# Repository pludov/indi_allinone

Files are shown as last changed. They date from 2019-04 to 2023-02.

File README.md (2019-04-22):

# INDI AllInOne Arduino driver

## Introduction

This project provides software + hardware instructions to build a powerfull astronomy tool for astrophotography, including focuser, filterwheel, dew heater, humidity sensor, ...

All that hardware is driven by a single Teensy 3.2 board (any 3.3v Arduino with > 32k memory and enough PINs should do it. Mega2560 is also possible with small adaptations to the schematics for 5v).

Contrary to most similar projects, the logic is fully operated within the micro-controler, so it is very easy to add/modify features. There is no ping-pong between firmware and driver. That also means that you can quickly write code for new hardware without knowing too much about INDI driver. Exposes an INDI property, write code that reacts to its change and you're done. And thanks to the INDI protocol, you'll end up with a UI integration within your favorite astro software !

It is intended to be used together with an ARM board, via serial TTL. However, it can be quickly adapted to run over usb serial as well.

I personnaly use it with [Mobindi](https://github.com/pludov/mobindi), my other Astrophoto project, making a full lightweight astro setup, controlled from a single mobile phone.

## Quick start

### Building/Customizing the firmware

The firmware can be compiled using the Arduino IDE, and source code is very modular, making it easy to add your own hardware (more/less dewheater, ...) If you want to do so, open ucontroler.ino and locate the function "declareHardware".

The setup includes:
* Focuser (unipolar motor)
* Fitlerwheel (unipolar motor with hall sensor)
* DHT22 sensor (temperature/humidity)
* 2x DewHeater (PWM with temperature sensor)
* Watt/Current metter to monitor power consumption
* A clock to report uptime (& detect reset/crash)

You can tweak motor acceleration/speed for focuser and filterwheel. The default is conservative, with lower speed for focuser retractation (usefull if you have a refractor)

If you want to adapt for an unsupported hardware, you'll need to write an event driven class (ie avoid blocking for more than about 1 ms, to keep filterwheel/focuser happy). A good starting point is Status.h/Status.cpp that just reports a numeric value.

Focuser.cpp also has a simple example of how to control something from INDI property.

### Building the indi driver

The indi driver is just a relay to the micro-controler, meaning you probably won't have to modify it.

To build, issue the commands:
```shell
cd indi_driver
mkdir build
cd build
cmake ..
make
sudo make install
```

You'll now have a indi_allinone driver installed.

### Building the hardware

The electronics schematic are provided for Teensy 3.2.

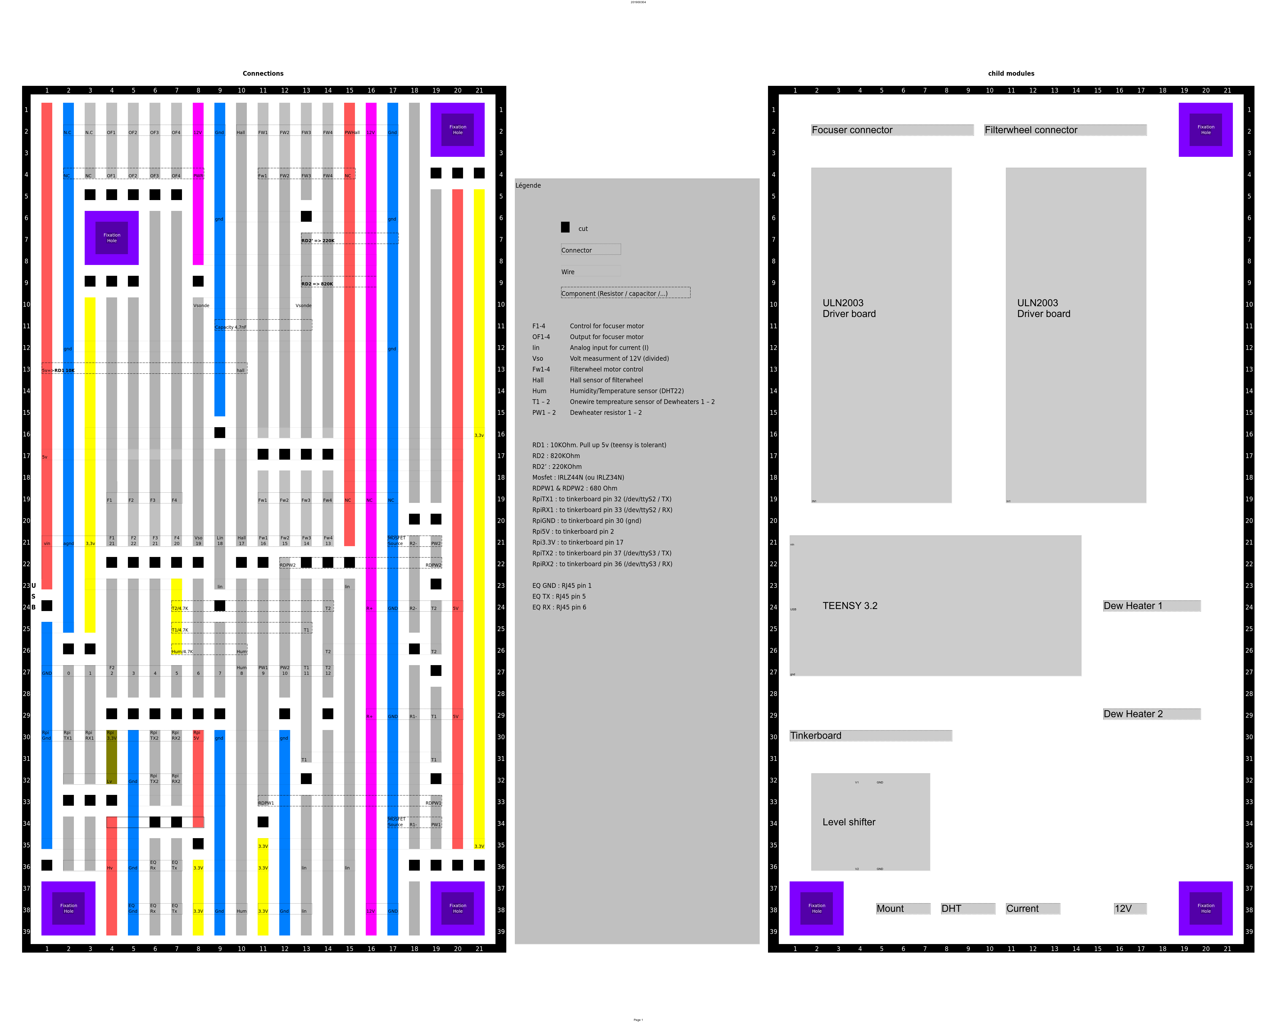
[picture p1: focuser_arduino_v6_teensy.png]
Schematics


The resulting board has roughtly the size of a raspberry pi, meaning you can probably stack them in a small box.

The filterwheel can be made from a manual filterwheel, adding a BYJ48 stepper and a hall sensor + magnet for calibration.
More details here (french) : http://pludov.blogspot.com/2016/08/roue-filtre-motorisee-la-mecanique.html

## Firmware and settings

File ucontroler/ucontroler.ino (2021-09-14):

// Indi All-in-one Arduino Driver
// @2019 Ludovic Pollet
//
// Release history:
// 
//------------------------------------------------------------------

#include <Arduino.h>


// Include necessary libraries
#include <OneWire.h>                          // DS18B20 temp sensor
#include <DallasTemperature.h>                // DS18B20 temp sensor
#include <EEPROM.h>                           // EEPROM Library

#include "CommonUtils.h"
#include "EepromStored.h"
#include "IndiProtocol.h"
#include "ScheduledIndiProtocol.h"
#include "IndiVector.h"
#include "IndiVectorMember.h"
#include "XmlWriteBuffer.h"
#include "BinSerialReadBuffer.h"

#include "utime.h"
#include "BaseDriver.h"
#include "Focuser.h"
#include "FilterWheel.h"
#include "Scheduler.h"
#include "pwmresistor.h"
#include "Status.h"
#include "MeteoTemp.h"
#include "DewHeater.h"
#include "WattMeter.h"


// --------------------------------------------------------------
// Declaration of hardware interfaces
// --------------------------------------------------------------
void declareHardware(BaseDriver * baseDriver) {

	// DHT22 sensor on pin8
	MeteoTemp * meteoTemp = new MeteoTemp(8, DHT22);

	// DewHeater with sensor on pin 11 & pwm on pin 9
	DewHeater * dw = new DewHeater(meteoTemp, 11, 9, 1);
	// another dewHeater with sensor on pin 12 & pwm on pin 10
	DewHeater * dw2 = new DewHeater(meteoTemp, 12, 10, 2);

	// Measure voltage on pin 5 and current on pin 4
	new WattMeter(5, 4, 0, EepromStored::Addr(1));

	// Focuser motor - 4 pins for motor control
	static const uint8_t focuserMotorPins[4] = { A6, A7, A8, A9 };
	new Focuser(baseDriver, EepromStored::Addr(4), focuserMotorPins, 0);

	// Focuser motor - 4 pins for motor control + 1 for hall sensor
	static const uint8_t filterWheelPins[5] = { 13, 14, 15, 16, 17};
	new FilterWheel(baseDriver, EepromStored::Addr(3), filterWheelPins, 0);

	// Report uptime
	new Status();
}

//------------------------------------------------------------------
// Setup
//------------------------------------------------------------------
void setup() {
	// initialize serial for ASCOM
	Serial.begin(115200);
	Serial1.begin(115200);
	DEBUG(F("Init!"));

	delay(500);

	BaseDriver * baseDriver = new BaseDriver();
	declareHardware(baseDriver);

	// Read eeprom
	EepromStored::init();

	// Let's talk packed indi over a serial link
#ifdef __AVR_ATmega2560__
	ScheduledIndiProtocol * serialWriter = new ScheduledIndiProtocol(&Serial);
#else
	ScheduledIndiProtocol * serialWriter = new ScheduledIndiProtocol(&Serial1);
#endif
	DEBUG(F("Welcome!"));
}

//------------------------------------------------------------------
// Main Loop
//------------------------------------------------------------------
void loop() {
	Scheduler::instance().loop();
}

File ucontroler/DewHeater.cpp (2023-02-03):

#include <Arduino.h>

#include "DewHeater.h"
#include "MeteoTemp.h"
#include "Utils.h"
#include "CommonUtils.h"
#include "EepromStored.h"
#include "IndiVectorMemberStorage.h"

#define STATUS_NEED_SCAN 0
#define STATUS_MEASURE 1
#define STATUS_IDLE 2

#define CONTROL_OFF 0
#define CONTROL_PWM_LEVEL 1
#define CONTROL_TARGET_TEMP 2
#define CONTROL_DEW_POINT_DELTA 2

#define STORED_ADDR_LENGTH 7
#define STORED_NAME_LENGTH 8

struct Settings {
	uint8_t opMode;
	uint8_t addr[STORED_ADDR_LENGTH];
	char name[STORED_NAME_LENGTH];
	float kp, ki, kd;
	float targetPwm, targetTemp, targetTempAbove;

	bool matchAddr(const uint8_t * taddr)
	{
		for(int i = 0; i < STORED_ADDR_LENGTH; ++i) {
			if (addr[i] != taddr[i]) return false;
		}
		return true;
	}

	void clearAddr()
	{
		for(int i = 0; i < STORED_ADDR_LENGTH; ++i) {
			addr[i] = 0;
		}
	}

	bool isEmptyAddr() {
		for(int i = 0; i < STORED_ADDR_LENGTH; ++i) {
			if (addr[i]) return false;
		}
		return true;
	}

	void setName(const char * v)
	{
		int i = 0;
		while(i < STORED_NAME_LENGTH) {
			char c = v[i];
			name[i] = c;
			i++;
			if (!c) break;
		}
		while(i < STORED_NAME_LENGTH) {
			name[i] = 0;
			i++;
		}
	}
};

const int storedSettingsCount = 3;

class DewHeatersMemory : public EepromStored {
private:
	static DewHeatersMemory * instance;
protected:

	virtual void decodeEepromValue(void * buffer, uint8_t sze){
		if (sze != getEepromSize()) {
			DEBUG(F("DewHeater EEPROM invalid size"), sze);
			return;
		}
		memcpy(settings, (void*)buffer, sze);
	}

	virtual void encodeEepromValue(void * buffer, uint8_t sze) {
		if (sze != getEepromSize()) return;
		memcpy(buffer, (void*)settings, sze);
	}

	virtual int getEepromSize() const {
		return sizeof(Settings) * storedSettingsCount;
	}

	// Bit mask of known slots (not saved)
	uint8_t slotSeen;
	Settings * settings;

	int8_t findPos(const uint8_t * addr) const
	{
		for(int i = 0; i < storedSettingsCount; ++i)
		{
			DEBUG(F("Eeprom: "), settings[i].addr[0], settings[i].addr[1], settings[i].addr[2], settings[i].addr[3], settings[i].addr[4]);
			if (settings[i].matchAddr(addr)) {
				return i;
			}
		}
		return -1;
	}

	int8_t findNewSlot() const
	{
		// Find an empty slot
		for(int i = 0; i < storedSettingsCount; ++i)
		{
			if (settings[i].isEmptyAddr()) {
				return i;
			}
		}

		// Select the last seen item ?
		for(int i = 0; i < storedSettingsCount; ++i) {
			if (!(slotSeen & (1 << i))) {
				return i;
			}
		}
		return 0;
	}

public:
	DewHeatersMemory(uint32_t addr): EepromStored(addr) {
		settings = new Settings[storedSettingsCount];
		slotSeen = 0;
	}

	void save(const Settings & newSettings)
	{
		int8_t slot = findPos(newSettings.addr);
		if (slot == -1) {
			slot = findNewSlot();
		}
		DEBUG(F("Saving to slot"), slot);
		// Don't overwrite now...
		slotSeen |= (1 << slot);
		memcpy((void*)(settings + slot), (const void*)&newSettings, sizeof(Settings));

		write();
	}

	void forget(uint8_t * addr)
	{
		int8_t slotId = findPos(addr);
		if (slotId == -1) {
			return;
		}
		// Just clear the addr
		settings[slotId].clearAddr();
		write();
	}


	const Settings * find(uint8_t * addr)
	{
		DEBUG(F("Looking for "), addr[0], addr[1], addr[2], addr[3], addr[4]);
		int8_t slotId = findPos(addr);
		if (slotId == -1) {
			return nullptr;
		}
		slotSeen |= (1 << slotId);
		return settings + slotId;
	}

	static DewHeatersMemory * getInstance() {
		if (instance == nullptr) {
			instance = new DewHeatersMemory(EepromStored::Addr(2));
		}
		return instance;
	}
};

DewHeatersMemory * DewHeatersMemory::instance = nullptr;



// Operating modes:
//   - Forced (targetPwm 0 -> 100%)
//   - target temperature (use pid to targetTemp)
//   - above dew point (use pid to stay a fixed °C above dewpoint
// This misses a "save" button
DewHeater::DewHeater(MeteoTemp * meteoTemp, uint8_t pin, uint8_t pwmPin, int suffix)
    :Scheduled(F("DewHeater")),
    group(Symbol(F("DEW_HEATER"), suffix)),

	statusVec(group, Symbol(F("DEW_HEATER_INFO_TEMP"), suffix), F("HW Temperature")),
    temperature(&statusVec, F("DEW_HEATER_TEMP_VALUE"), F("Readen Temper (C)"),-273.15, 100, 1),
    pwm(&statusVec, F("DEW_HEATER_PWM_LEVEL"), F("Power applied (%)"),0, 100, 1),
	dynTargetTemp(&statusVec, F("DEW_HEATER_CURR_TARGET_TEMP"), F("Target Temp (C)"), -273.15, 100, 1),

    uidVec(group, Symbol(F("DEW_HEATER_INFO_UID"), suffix), F("Unique Identifier")),
    uid(&uidVec, F("DEW_HEATER_UID_VALUE"), F("Unique Identifier"),12),

    nameVec(group, Symbol(F("DEW_HEATER_INFO_NAME"), suffix), F("Label"), VECTOR_WRITABLE|VECTOR_READABLE),
    name(&nameVec, F("DEW_HEATER_INFO_NAME"), F("Label"),STORED_NAME_LENGTH),

	powerMode(group, Symbol(F("DEW_HEATER_POWER_MODE"), suffix), F("Power Mode"), VECTOR_WRITABLE|VECTOR_READABLE),
	powerModeOff(&powerMode, F("POWER_MODE_OFF"), F("Off")),
	powerModeForced(&powerMode, F("POWER_MODE_FORCED"), F("Forced")),
	powerModeByTemp(&powerMode, F("POWER_MODE_BY_TEMP"), F("Target temp")),
	powerModeOverDew(&powerMode, F("POWER_MODE_OVER_DEW"), F("Follow dew point")),


	targetPwmVec(group, Symbol(F("DEW_HEATER_TARGET_PWM"),suffix), F("Fixed Power"), VECTOR_WRITABLE|VECTOR_READABLE),
	targetPwm(&targetPwmVec, F("TARGET_PWM"), F("0-100"), 0, 100, 0.1),

	targetTempVec(group, Symbol(F("DEW_HEATER_TARGET_TEMP"),suffix), F("Fixed Temperature"), VECTOR_WRITABLE|VECTOR_READABLE),
	targetTemp(&targetTempVec, F("TARGET_TEMPERATURE"), F("C"), -100, 100, 0.1),

	targetTempAboveVec(group, Symbol(F("DEW_HEATER_TARGET_TEMP_ABOVE_DP"),suffix), F("Above Dew Point"), VECTOR_WRITABLE|VECTOR_READABLE),
	targetTempAbove(&targetTempAboveVec, F("TARGET_TEMPERATURE_ABOVE_DP"), F("C"), -100, 100, 0.1),

	settingKpVec(group, Symbol(F("DEW_HEATER_PID_P"), suffix), F("PID Settings - P"), VECTOR_WRITABLE|VECTOR_READABLE),
	settingKp(&settingKpVec, F("P"), F("P"), -1000, 1000, 0.1),

	settingKiVec(group, Symbol(F("DEW_HEATER_PID_I"), suffix), F("PID Settings - I"), VECTOR_WRITABLE|VECTOR_READABLE),
	settingKi(&settingKiVec, F("I"), F("I"), -1000, 1000, 0.1),

	settingKdVec(group, Symbol(F("DEW_HEATER_PID_D"), suffix), F("PID Settings - D"), VECTOR_WRITABLE|VECTOR_READABLE),
	settingKd(&settingKdVec, F("D"), F("D"), -1000, 1000, 0.1),

	configOperationVec(group, Symbol(F("DEW_HEATER_CONFIG_OPERATION"), suffix), F("Eeprom"), VECTOR_WRITABLE|VECTOR_READABLE),
	configIdle(&configOperationVec, F("IDLE"), F("Idle")),
	configSave(&configOperationVec, F("SAVE"), F("Save")),
	configForget(&configOperationVec, F("FORGET"), F("Forget")),
	configReload(&configOperationVec, F("RELOAD"), F("Reload")),

    oneWire(pin)
{
	this->meteoTemp = meteoTemp;
    this->priority = 2;
    this->status = 0;
    this->pwmPin = pwmPin;
    this->failed();
    this->nextTick = UTime::now();
    ITerm = 0;
    pidRunning = false;
    pidDisabled = false;
    tempAvailable = false;
    lastTime = 0;
    lastInput = 0;
    ITerm = 0;

    // Ensure config item is available
    DewHeatersMemory::getInstance();
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

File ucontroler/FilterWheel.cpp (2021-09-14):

#ifdef ARDUINO
#include <Arduino.h>
#endif

#include <string.h>

#include "CommonUtils.h"
#include "FilterWheel.h"
#include "BaseDriver.h"
#include "EepromStored.h"
#include "IndiVectorMemberStorage.h"

#define DEFAULT_MOTOR_PULSE 4000

#define POS_INVALID ((uint32_t)0x7fffffff)

struct Settings {
	uint32_t pos;
    // Base of the last calibration
    uint8_t base;
};

class FilterWheelMemory : public EepromStored {
protected:
	virtual void decodeEepromValue(void * buffer, uint8_t sze){
		if (sze != sizeof(Settings)) {
			DEBUG(F("FilterWheel EEPROM invalid size"), sze);
			return;
		}
		memcpy(&settings, (void*)buffer, sze);
	}

	virtual void encodeEepromValue(void * buffer, uint8_t sze) {
		if (sze != sizeof(Settings)) return;
		memcpy(buffer, (void*)&settings, sze);
	}

	virtual int getEepromSize() const {
		return sizeof(Settings);
	}
public:
	// Bit mask of known slots (not saved)
	Settings settings;

	FilterWheelMemory(uint32_t addr): EepromStored(addr) {
		settings.pos = POS_INVALID;
        settings.base = 0;
	}

	void save()
	{
		write();
	}
};

FilterWheel::FilterWheel(BaseDriver * bd, uint32_t addr, const uint8_t* pins, int suffix)
:
    Motor(pins, F("Filterwheel"), DEFAULT_MOTOR_PULSE, DEFAULT_MOTOR_PULSE),
    group(Symbol(F("FILTERWHEEL"), suffix)),
    filterSlotVec(group, Symbol(F("FILTER_SLOT"), suffix), F("Filter Slot"), VECTOR_WRITABLE|VECTOR_READABLE),
    filterSlot(&filterSlotVec, F("FILTER_SLOT_VALUE"), F("Filter"), 0, FILTER_SLOT_COUNT - 1, 1),
    rawPosVec(group, Symbol(F("FILTER_RAW_POSITION"), suffix), F("Raw Position"), VECTOR_WRITABLE|VECTOR_READABLE),
    rawPos(&rawPosVec, F("FILTER_RAW_POSITION"), F("Ticks"), 0, 100000, 1),
    motorSettingsVec(group, Symbol(F("FILTER_MOTOR_SETTINGS"), suffix), F("Motor settings"), VECTOR_WRITABLE|VECTOR_READABLE),
    motorPulse(&motorSettingsVec, F("FILTER_MOTOR_PULSE"), F("pulse (ms)"), 100,100000, DEFAULT_MOTOR_PULSE),
    motorBacklash(&motorSettingsVec, F("FILTER_MOTOR_BACKLASH"), F("backlash"), -10000,10000, 0),
    calibrateVec(group, Symbol(F("FILTER_CALIB"), suffix), F("Calibration"), VECTOR_WRITABLE|VECTOR_READABLE|VECTOR_SWITCH_ATMOSTONE),
    calibrate(&calibrateVec, F("CALIB"), F("Calibrate")),
    abortMotionVec(group, Symbol(F("FILTER_ABORT_MOTION"), suffix), F("Abort Motion"), VECTOR_WRITABLE|VECTOR_READABLE|VECTOR_SWITCH_ATMOSTONE),
    abortMotion(&abortMotionVec, F("ABORT"), F("Abort")),
    filterNamesVec(group, Symbol(F("FILTER_NAME"), suffix), F("Names"), VECTOR_WRITABLE|VECTOR_READABLE),
    filterPositionsVec(group, Symbol(F("FILTER_POS")), F("Positions"), VECTOR_WRITABLE|VECTOR_READABLE),
    hallVec(group, Symbol(F("FILTER_HALL"), suffix), F("Hall sensor"), VECTOR_READABLE),
    hall(&hallVec, Symbol(F("HALL_VALUE")), F("Value"),0 ,255, 1),
    eepromReadyListener(EepromCallback(&FilterWheel::loadInitialSettings, this))
{
    memory = new FilterWheelMemory(EepromStored::Addr(addr, 47));
    pauseAfterMove = 100;
    maxAccelStep = 30;
    for(int i = 0; i < FILTER_SLOT_COUNT; ++i) {
        filterNames[i] = new IndiTextVectorMember(&filterNamesVec,
                                        Symbol(F("FILTER_SLOT_NAME_"), i+1),
                                        Symbol(F("Filter"), i+1),
                                        9);
        IndiVectorMemberStorage::remember(filterNames[i], EepromStored::Addr(addr, 56+i));
        filterPositions[i] = new IndiIntVectorMember(&filterPositionsVec,
                                        Symbol(F("FILTER_SLOT_POS_"), i+1),
                                        Symbol(F("Filter"), i+1),
                                        0,
                                        100000,
                                        1);
        IndiVectorMemberStorage::remember(filterPositions[i], EepromStored::Addr(addr, 48+i));
    }
    IndiVectorMemberStorage::remember(&motorPulse, EepromStored::Addr(addr, 46));
    IndiVectorMemberStorage::remember(&motorBacklash, EepromStored::Addr(addr, 45));
    this->currentCalibration = CALIBRATION_IDLE;

    pinMode(this->motorPins[4], INPUT);
    loadPosition(50000, 0);
    onProgress();
    rawPosVec.onRequested(VectorCallback(&FilterWheel::rawPosChanged, this));
    filterSlotVec.onRequested(VectorCallback(&FilterWheel::filterSlotChanged, this));
    motorSettingsVec.onRequested(VectorCallback(&FilterWheel::motorSettingsChanged, this));
    abortMotionVec.onRequested(VectorCallback(&FilterWheel::abortChanged, this));
    calibrateVec.onRequested(VectorCallback(&FilterWheel::calibrateChanged, this));
    bd->addCapability(FILTER_INTERFACE);
}

void FilterWheel::loadInitialSettings()
{
    if (memory->settings.pos == POS_INVALID) {
        // Will stay idle in calibration state
        this->currentCalibration = 2;
    } else {
        this->currentCalibration = CALIBRATION_IDLE;
        loadPosition(memory->settings.pos, memory->settings.base);
        if (this->isMoving()) {
            setTargetPosition(getCurrentPosition());
        }
    }
    this->motorSettingsChanged();
    onProgress();
}

void FilterWheel::rawPosChanged() {
    if (this->currentCalibration) {
        // Busy - Ignore for now
        return;
    }
    gotoRawPos(rawPos.getValue());
}

void FilterWheel::gotoRawPos(int32_t target) {
    int32_t backlash = motorBacklash.getValue();
    int32_t intermediate = target;
    int32_t current = getCurrentPosition();
    if (backlash != 0) {
        if (backlash > 0) {
            if (target < current) {
                intermediate = target - backlash;
                if (intermediate < 0) {
                    intermediate = 0;
                }
            }
        } else {
            if (target > current) {
                intermediate = target - backlash;
            }
        }
    }
    if (target < 0) {
        target = 0;
    }
    if (intermediate < 0) {
        intermediate = 0;
    }
    this->setTargetPosition(target, intermediate);
}

void FilterWheel::motorSettingsChanged() {
    this->updatePulse(motorPulse.getValue(), motorPulse.getValue());
}

void FilterWheel::filterSlotChanged() {
    if (this->currentCalibration) {
        // Busy - ignore for now
        return;
    }
    int32_t newValue = filterSlot.getValue();
    if (newValue < 1 || newValue > FILTER_SLOT_COUNT) {
        newValue = 1;
        filterSlot.setValue(1);
    }
    int32_t target = filterPositions[newValue - 1]->getValue();
    gotoRawPos(target);
}

void FilterWheel::abortChanged() {
    if (this->abortMotion.getValue()) {
        abortMotion.setValue(false);
        this->currentCalibration = CALIBRATION_IDLE;
        if (this->isMoving()) {
            setTargetPosition(getCurrentPosition());
        }
        onProgress();
    }
}

bool FilterWheel::readPin() {
    return digitalRead(this->motorPins[4]);
}
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

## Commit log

2017-11-08 Migrated from previous code => compilate on Teennsy (probably broken)
    [MeteoTemp.cpp, Motor.cpp]
2017-11-10 Version limitée qui s'execute sur teensy
2017-11-10 Notification des changements sur les variables
2017-11-11 DS18b20 sensor driver
2017-11-11 DewHeater now reports UID of the sensor
2017-11-12 New PWM display
2017-11-12 Indi driver skeleton
2017-11-12 indi driver exposes serial connection parameters
2017-11-12 Demo for code sharing between arduino and indi driver
2017-11-17 Isolate XML code (debug on arduino)
2017-11-18 Bi-di comm, not ready
2017-11-19 Fix random data corruption + debug on Serial1
    [DewHeater.cpp, MeteoTemp.cpp, Motor.cpp]
2017-11-25 Properties are now removed on disconnect (+processing threads stop before closing serial)
2017-11-26 Support for switch vector (one of many only)
2017-11-26 DewHeater uses a switch
2017-11-26 Symbol now has its own class for Arduino and Indi driver
2017-11-26 Correct handling of group attribute of properties
    [DewHeater.cpp]
2017-12-02 Read dht22 sensor info
2017-12-09 Compilation fix for Eeprom on Teensy
2017-12-19 DewHeater and Meteo sensor progress
2017-12-19 USB serial is now for DEBUG only. Rely on HW serial 1 for Tinker board comm
2017-12-21 PID implementation for dew heater
2017-12-27 DewHeater: identify heaters using sensor unique id
2018-02-24 Fix dew heater identification: Limit eeprom items to approx ~255 bytes
2018-03-11 Fix DEW HEATER memory
    [DewHeater.cpp]
2018-09-29 Send debug logs from driver to indiserver
2018-12-15 Reports driver interface for Focuser
2018-12-31 Support for vector of independant switches
2019-04-19 FilterWheel without calibration and pos memory
2019-04-19 FilterWheel: calibration ok. Now misses backlash setting
    [FilterWheel.cpp]
2019-04-20 Fix filterwheel writing to eeprom before eeprom init
    [FilterWheel.cpp]
2019-04-21 Filterwheel sets filter pos on startup from EEPROM
2020-07-31 Fix obvious compilation problems not reported until now
    [Motor.cpp, ucontroler.ino]
2021-06-26 Fix for negative temperature
    [DewHeater.cpp]
2021-06-26 Attempt to handle motor backlash for fw
    [FilterWheel.cpp, Motor.cpp]
2021-06-27 Indi settings for FW motor (speed, backlash)
    [FilterWheel.cpp]
2021-06-27 Filterwheel keeps the low 8 bits accross calibration
    The state of the motor was discard after calibration.
    This was introducing 7/8 * 360° of imprecision on the motor axis.
    We are now limited to accuracy of gear box.
2021-09-14 Apply backlash when manually stepping filterwheel
    [FilterWheel.cpp]
2021-09-14 Fix micro step precision accros restart
    [Motor.cpp]
2021-09-14 Fix memory used before allocation
    [FilterWheel.cpp, Focuser.cpp]
2023-02-03 Motor config for the focuser
2023-03-19 A first plateform.IO convertion
2023-03-19 Compil but do not run on pico
2023-03-26 Fix disconnection of the indi driver
2023-04-01 Force default pwm to 255 on pico
2023-04-02 Keep heater measure under 1ms
2023-04-08 Run with 2 uart over usb (proto & debug)
2023-04-08 Fix DHT code hanging on pico
    [MeteoTemp.cpp]
2023-04-08 Distinct meteo drivers for BME & DHT
2023-11-02 Schematics for new board
    [AstroController2_20231102_1.fzz, Filterwheel.fzz, Focuser.fzz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]
2023-11-03 Preliminary case
    [case.scad]
2023-11-03 case progress
    [case.scad]
2023-11-04 Case is complete (untested)
    [case.scad]
2023-11-04 Case: RJ window, try 2
    [case.scad]
2023-11-04 Vixen fixation
    [case.scad]
2023-11-05 Everything laid out for case
    [case.scad]
2023-11-10 Stronger cover
    [case.scad]
2023-11-17 Extract the meteo opening for faster print
    [case.scad]
2023-11-19 Case improvment following first printing
    [case.scad]
2023-11-22 Usb hole for cable prevents collision with sadle
    [case.scad]
2023-11-22 Adjust pins for the pico version
2023-12-18 Heater schematics update
    [Heather-connection.fzz]
2023-12-22 Pico: put code into RAM to allow transparent flash access
2023-12-22 Pico: blink a led to notify status
2023-12-22 Use latest pico hardware
2023-12-22 Tickness of PCB
    [case.scad]
2023-12-22 Button to reboot in firmware mode
2024-01-17 Temperature compensation on the meteo sensor
2025-07-29 Hub support
    [support_hub.scad]
2025-08-02 Remove RJ45 & adapt to DC adapteur from amazon
    https://www.amazon.fr/dp/B08T8658H8?ref=ppx_yo2ov_dt_b_fed_asin_title&th=1
    [case.scad]
2025-08-02 System de fixation pour le petit hub
    Beaucoup plus simple. On laisse deux trou dans le boitier pour des languettes
    [case.scad]
2025-08-02 Fixation vixen via adaptateur rouge
    [case.scad]
2025-08-02 Vertical align of the usb hub fixation
    [case.scad]
2025-08-03 Fix vixen screws not traversing the cover
    [case.scad]
2025-08-03 Fix hub width evaluation
    [case.scad]
2025-08-03 Fixation pour le hub 4 ports (à base de visses M3)
    [support_hub_4port.scad]
2025-08-04 Revert "Pico: put code into RAM to allow transparent flash access"
    This reverts commit 54ab543043aa375021bdc66cfa374e6f61d51514.
    Flash function anyway force the other core to go idle. Better have serialization
    of the time critical method in core1 + live with the occasional ms delay on core0
2025-08-06 Reapply "Pico: put code into RAM to allow transparent flash access"
    This reverts commit 46dce69b1fb030674e0735f3b8249f9617d5974a.
2025-08-06 Adapting the ld script to latest pico framework version
    * Renommer text en flashtext
    flashtext: il n'y a pas de > FLASH coté copy_to_ram. C'est bizarre. Je l'ai laissé
    * et en retirer tout après (*(.reset))
    * retirer rodata de rodata
    remarque il y a aussi big_const. Verifier qu'on va le mettre
    * Mettre un .text just avant .data (verbatim par rapport à la version du sdk pico)
    => dedans il y a __ram_text_start__, __ram_text_end__, ... quoi en faire ?
    Ils sont probablement inutilisés.
    * à la fin du data, on ajoute les pre-init, init et f-init
    * .bss passe en LOAD.
2025-08-07 Ignore stl files
2025-08-07 BME sensor tries both i2c addresses
2025-08-07 Fix a potential bug with NAN (when meteo sensor malfunctions)
2025-08-09 Print RJ12 window
2025-08-09 Adaptation du support bme au nouveau PCB
2025-08-10 Pad de 3mm, un peu trop petit
